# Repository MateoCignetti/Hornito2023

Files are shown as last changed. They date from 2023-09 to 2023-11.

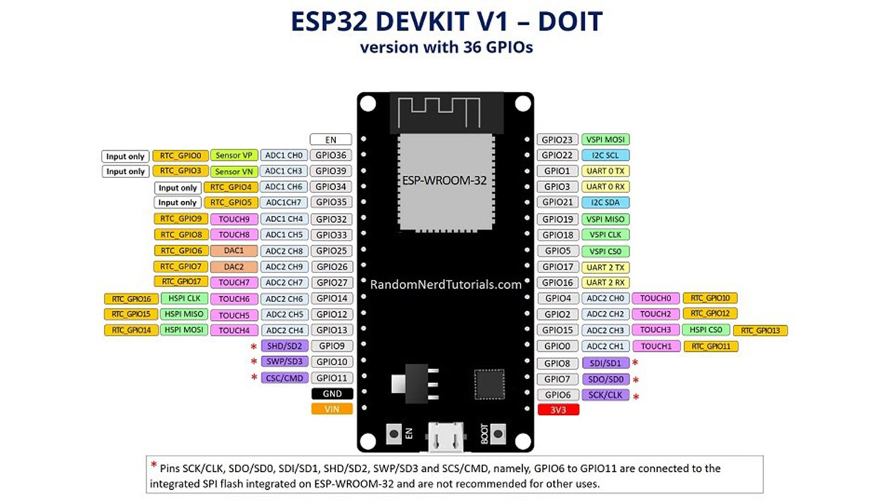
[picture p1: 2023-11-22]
Recursos/Esp32/esp32-devkit-v1-pinout.jpg

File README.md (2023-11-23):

## Trabajo práctico final de Técnicas Digitales III y Medidas Electrónicas II. UTN FR San Francisco

En este repositorio se encuentran subidos todos los archivos relacionados al trabajo práctico final las materias Técnicas Digitales III y Medidas Electrónicas II. Contiene archivos de programación de los microcontroladores, esquemáticos del circuito y de pcb, y recursos varios.

## Autores

- [ ] Alesandria, Alejo
- [ ] Cignetti, Mateo
- [ ] Delfino, Ramiro
- [ ] Galliano, Ignacio
- [ ] Rinaudo, Facundo
- [ ] Rodriguez, Manuel

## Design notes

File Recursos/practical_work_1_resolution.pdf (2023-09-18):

# Control de Potencia mediante TRIAC

Díaz, Matías - matidiaz2313@hotmail.com Previotto, Santiago – santiagopreviotto@gmail.com Ingeniería Electrónica - UTN Facultad Regional San Francisco Electrónica de Potencia – Ing. Giorgis, Alejandro

RESUMEN

A lo largo de este práctico podremos controlar la potencia administrada a una carga de tensión alterna mediante el uso de TRIAC. Para ello se tiene en cuenta la naturaleza de dicha carga como así también la potencia a controlar, para poder dimensionar el circuito de manera adecuada.
Palabras claves: TRIAC, potencia, carga, control.

INTRODUCCIÓN

Un TRIAC o Triodo para Corriente Alterna es un dispositivo semiconductor, de la familia de los tiristores. La diferencia con un tiristor convencional es que este es unidireccional y el TRIAC es bidireccional. De forma coloquial podría decirse que el TRIAC es un interruptor capaz de conmutar la corriente alterna.

Figura 1: Símbolo y estructura interna.

El TRIAC consta de 3 terminales y su estructura interna está compuesto por 4 capas que consta de seis regiones de dopado. El terminal definido como GATE está diseñado con el fin de que tenga contacto óhmico con las regiones N y P. Esto ayuda a que el dispositivo se active con polaridades positivas y negativas, es decir, como un arreglo de dos tiristores en antiparalelo.

La versatilidad del TRIAC y la simplicidad de su uso lo hace ideal para una amplia variedad de aplicaciones relacionadas con el control de corrientes alternas. Una de ellas es su utilización como interruptor estático ofreciendo muchas ventajas sobre los interruptores mecánicos convencionales, que requieren siempre el movimiento de un contacto, siendo la principal, la que se obtiene como consecuencia de que el TRIAC siempre se dispara cada medio ciclo cuando la corriente pasa por cero, con lo que se evitan los arcos y sobre tensiones derivadas de la conmutación de cargas inductivas que almacenan una determinada energía durante su funcionamiento. A continuación, se muestran algunas características importantes sobre los TRIAC:

- El TRIAC conmuta del modo de corte al modo de conducción cuando se inyecta corriente a la compuerta. Después del disparo la compuerta no posee control sobre el estado del TRIAC. Para apagar el TRIAC la corriente anódica debe reducirse por debajo del valor de la corriente de retención Iℎ.
- La corriente y la tensión de encendido disminuyen con el aumento de temperatura y con el aumento de la tensión de bloqueo.
- La aplicación del TRIAC, a diferencia del Tiristor, se encuentra básicamente en corriente alterna. Su curva característica refleja un funcionamiento muy parecido al del tiristor apareciendo en el primer y tercer cuadrante del sistema de ejes. Esto es debido a su bidireccionalidad.
- La principal utilidad del TRIAC es como regulador de potencia entregada a una carga, en corriente alterna.

Para poner en funcionamiento el mismo, se debe enviar un pulso de activación a través del terminal gate. Si el TRIAC está apagado no hay circulación de corriente entre las terminales MT2 y MT1 sin importar la polaridad del voltaje que se le aplique externamente. Para este caso, el TRIAC se comporta como un circuito abierto. Si el TRIAC está encendido, hay una condición de circulación de corriente de una terminal a la otra, esto depende de la polaridad del voltaje aplicado externamente. En el momento en que el voltaje en MT2 se hace más positivo, entonces la corriente circula de MT2 a MT1. En el momento en que el voltaje en MT1 se hace más positivo, entonces la corriente circula de MT1 a MT2. Para estas condiciones de operación el TRIAC se comporta como un interruptor cerrado.

Un optotriac (también conocido como optoacoplador) es un dispositivo que utiliza un TRIAC en su estructura interna, el cuál es activado mediante una luz infrarroja emitida por un fotodiodo hacia la gate del mismo. Cuando esta luz es interrumpida o bloqueada, el circuito se abre actuando como un interruptor abierto.
También, un optoacoplador puede contar en su estructura interna de un transistor como el PC817. Cuando se manda un pulso externo al fotodiodo, se emite un haz de luz a la base de un transistor interno, este se satura y entra en estado de conducción entre colector y emisor. Para este caso la impedancia entre colector y emisor es baja. Cuando no hay emisión de luz infrarroja, el fototransistor tiene alta impedancia entre colector y emisor y este no entra en conducción.

Figura 2: Optotransistor y optotriac.

DESARROLLO

Se propone realizar un controlador de potencia entregada a una carga, conocido comúnmente como dimmer. Se busca utilizar un circuito optoacoplador para separar la electrónica de control de la de potencia.
Para ello se selecciona el optoacoplador MOC3021, el cual es un optotriac, para controlar el ángulo de disparo y así la potencia en la carga. Además, se necesita un circuito de detección de cruce por cero, debido a que, por el lado del control, se debe conocer cuando la señal de alterna pasa por cero para tener la referencia y producir dicho disparo. Se utiliza un optoacoplador PC817, que es un optotransistor que conduce o no de acuerdo a si hay o no presencia de señal de potencia.
Según la hoja de datos del fabricante, el circuito de aplicación típico para el MOC3021 es el siguiente:

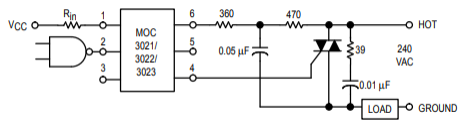
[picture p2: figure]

Figura 3: Aplicación típica del MOC3021.

El circuito consta de dos redes Snubber, una para proteger el TRIAC interno del MOC3021 (resistencia de 470 Ω y capacitor de 0.05 μF) y en la otra para proteger el TRIAC que manipula la carga (resistencia de 39 Ω y capacitor de 0.01 μF). Cabe aclarar que una red Snubber es un arreglo de elementos que sirve como protección del semiconductor de potencia ante las conmutaciones de conducción a no conducción y viceversa, soportando las variaciones bruscas de tensión que se producen, estas pueden estropear al dispositivo en cuestión. Para simplificar el circuito, se utiliza una única red Snubber RC para la protección del TRIAC que manipula la lámpara.
La carga a utilizar es una lámpara incandescente de 220 V − 42 W, debido a su naturaleza no se necesita manipular grandes corrientes, por lo que un TRIAC como el BT137 es más que suficiente y posee

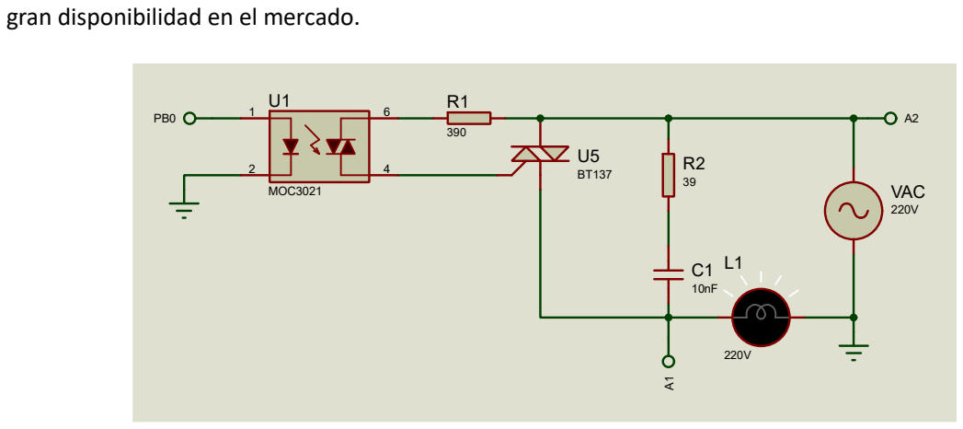
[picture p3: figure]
gran disponibilidad en el mercado.

Figura 4: Circuito de potencia.

A través del pin PB0 podemos controlar el optotriac MOC3021, este dispara la compuerta del TRIAC BT137 cuando se detecta el cruce por cero, la resistencia R1 limita la corriente que circula por la compuerta del mismo. Se conecta una red Snubber en paralelo al TRIAC, esta suprime corrientes no deseadas introducidas por la carga resistiva, las cuales pueden disparar el TRIAC en cualquier momento y causar problemas de operación.

Para el circuito de detección de cruce por cero, utilizamos un trasformador 220 V – 12 V para ingresar con una tensión más segura al optotransistor PC817. En el siguiente circuito, se puede observar la

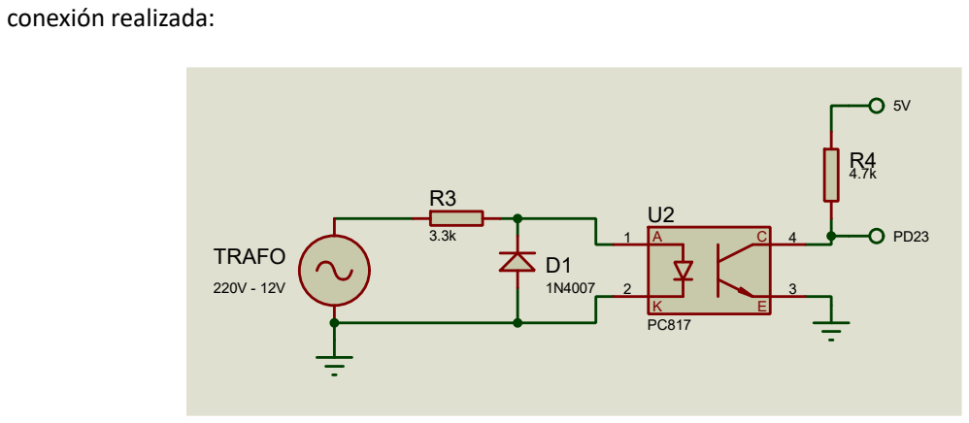
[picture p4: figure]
conexión realizada:

Figura 5: Circuito detector de cruce por cero.

Cuando la señal alterna está en un semiciclo positivo, el fototransistor se polariza, entrando en corte debido a que no hay diferencia de tensión entre colector y emisor, en cambio, con la señal alterna en un semiciclo negativo, el optotransistor no se polariza existiendo una diferencia de potencial entre el colector y emisor de VCC. El Diodo 1N4007 se encarga de proteger al optoacoplador de los semiciclos negativos y la resistencia de 3300 Ω limita la corriente por el mismo.

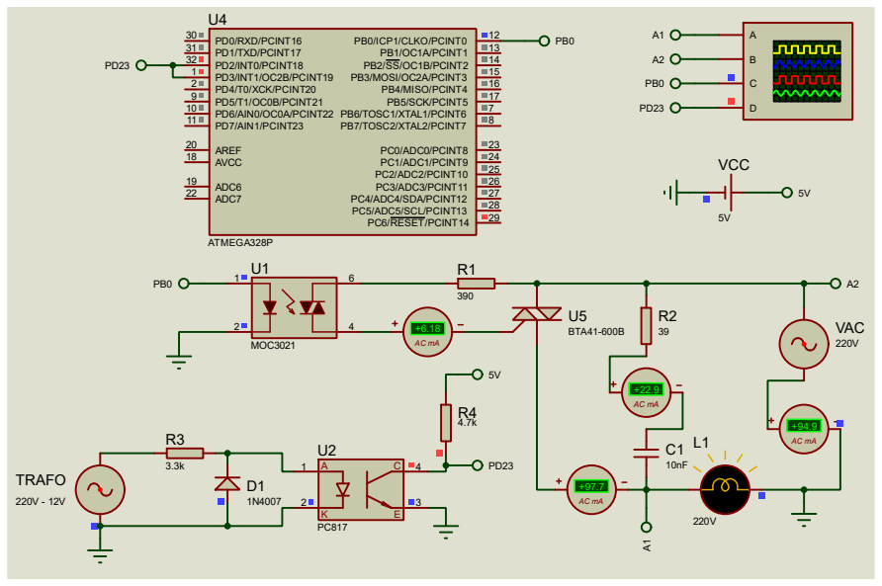
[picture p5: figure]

Figura 6: Diseño de circuito en Proteus con corrientes.

Se plantea el circuito de la figura 6 de control de potencia y se simula mediante el software Proteus, para poder observar que corrientes circulan por cada elemento y poder dimensionar correctamente los resistores y corroborar la selección del TRIAC. Cabe aclarar que el TRIAC BT137 no está disponible en el software, por lo que se selecciona el BTA41-600B de características similares.

La potencia que tiene que disipar la resistencia de la red Snubber es:

PR39 = (20 mA)

2 × 39 Ω = 15.6 mW

Por otro lado, la resistencia que limita la corriente por la compuerta del TRIAC tiene una potencia de:

PR390 = (6 mA)

2 × 390 Ω = 14.04 mW

Mediante esta última resistencia, se limita la corriente por la gate a 6 mA, lo cuál está dentro del valor recomendado por el fabricante.

IGT | Corriente de disparo de la gate | VD = 12 V; IT = 0.1 A; T2+ G+; Tj = 25 °C | 10 mA

La corriente por los terminales T1 y T2 del BT137 es aproximadamente 100 mA, de esta forma podemos decir que estamos dentro de los parámetros establecidos por el fabricante que plantea como máximo una corriente por terminales de 8 A.

IT(RMS) | Corriente RMS | Full sine wave; Tmb ≤ 102 °C | 8 A

Entonces teniendo las potencias disipadas, se buscan resistencias de 1/4 W, suficientes para manipular las corrientes en juego.

Ahora teniendo en cuenta el funcionamiento de ambos circuitos, tanto el de control de potencia como el de detección de cruce por cero, se necesita diseñar un programa para un microcontrolador capaz de controlar ambos circuitos. Se utiliza un microcontrolador de la marca Atmel, ATMEGA328P, posee 32kb de memoria flash, 2kb de memoria RAM y 1kb de EEPROM. Consta de 14 entradas/salidas digitales con 6 salidas PWM y 6 entradas analógicas. La siguiente ilustración describe la disposición de pines del mismo.

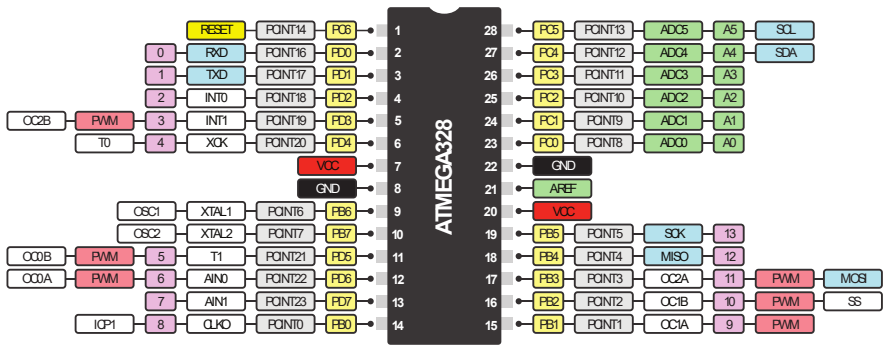
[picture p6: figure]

Figura 7: Pines del ATMEGA328P.

La idea principal del programa es evaluar el cruce por cero de la señal de control provista por el optoacoplador PC817 y en base a esto dar una señal al optoacoplador MOC3021 y así disparar el TRIAC. Entonces se utilizan dos interrupciones, INT0 e INT1, con la finalidad de detectar los flancos tanto de subida como de bajada de la señal del PC817. Luego ambas interrupciones realizan la misma secuencia, primero, un tiempo de espera que puede ser de hasta 10 ms, es decir la mitad del periodo de la onda de 50 Hz de alterna y luego, colocan en alto una salida digital PB0 durante 2 μs, tiempo recomendado de ancho del pulso para el disparo del BT137, según lo indica el fabricante. A continuación, se muestra el segmento de código en lenguaje C para el microcontrolador seleccionado.

/*
* Trabajo Práctico 1
* Electrónica De Potencia
* Ing. Giorgis, Alejandro
* UTN Facultad Regional San Francisco * Diaz, Matías; Previotto, Santiago
*/
/** \file main.c */

#define PRTC 50 // porcentaje de potencia entrada a la carga

/* librerías */
#include <avr/io.h>

#include <avr/interrupt.h>

#include <util/delay.h>

int main() {
cli(); | // desactiva las interrupciones globales
DDRB |= (1<<DDB0); // PB0 como salida (MOC3021) PORTB &=~ (1<<PORTB0); // PB0 inicializado en 0 DDRD &=~ (1<<DDD2); // PD2 como entrada (INT0)
DDRD &=~ (1<<DDD3); // PD3 como entrada (INT1)
// interrupción INT0 para flacos de subida
EICRA &=~ (1<<ISC00);
EICRA |= (1<<ISC01);
// interrupción INT1 para flacos de bajada EICRA |= (1<<ISC10);
EICRA |= (1<<ISC11);
// activación de INT0 e INT1
EIMSK |= (1<<INT0);
EIMSK |= (1<<INT1);
sei(); // activa las interrupciones globales while(1) {
}
return 0;
}

ISR(INT0_vect) { // rutina de interrupción INT0 _delay_us((int)(PRTC*(10000/100))
);
PORTB |= (1<<PORTB0);
_delay_us(2);
PORTB &=~ (1<<PORTB0);

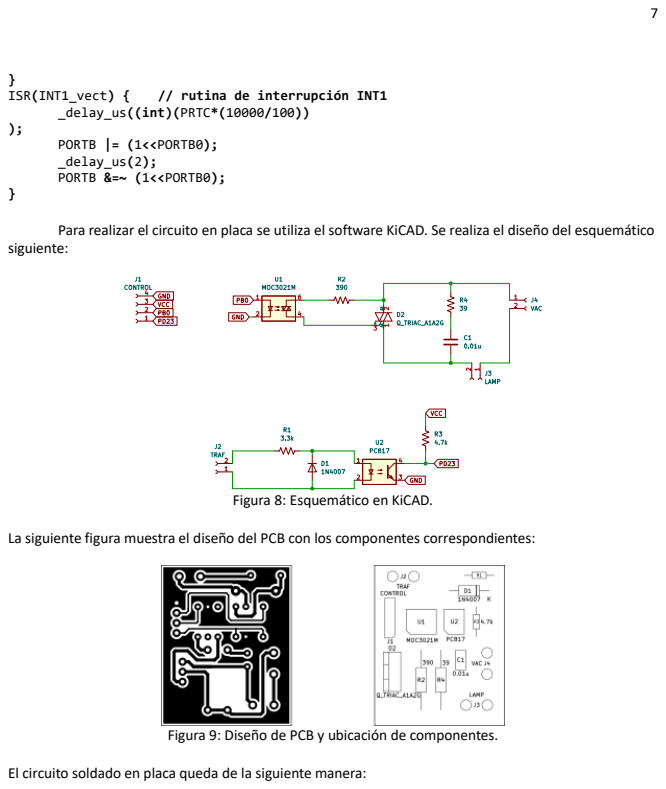
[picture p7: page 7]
ISR(INT1_vect) {; // rutina de interrupción INT1; _delay_us((int)(PRTC*(10000/100)); PORTB |= (1<<PORTB0); _delay_us(2); PORTB &=~ (1<<PORTB0);; siguiente:

Para realizar el circuito en placa se utiliza el software KiCAD. Se realiza el diseño del esquemático

Figura 8: Esquemático en KiCAD.

La siguiente figura muestra el diseño del PCB con los componentes correspondientes:

Figura 9: Diseño de PCB y ubicación de componentes.

El circuito soldado en placa queda de la siguiente manera:

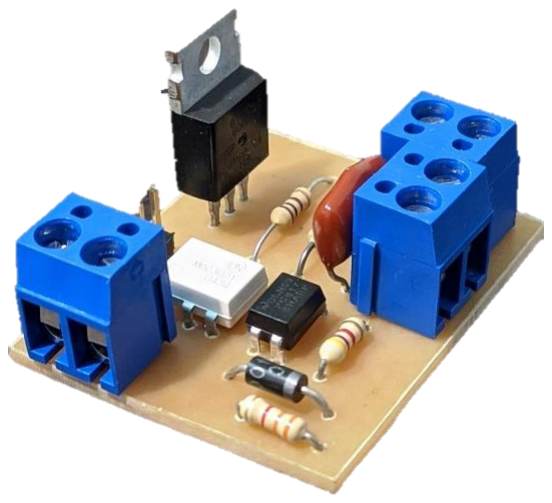
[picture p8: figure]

Figura 10: Placa terminada.

Para los ensayos de laboratorio se prueba primero el circuito de detección de cruce por cero, donde se utiliza un transformador de 220V-12V y la salida de control del PC817 conectada al microcontrolador en los pines PD2 y PD3 para detectar los flancos de subida y de bajada. Se mide con el osciloscopio el pulso en la salida PB0 del ATMEGA328P y se observa el pulso de 2 μs correspondiente, lo que verifica el funcionamiento óptimo.

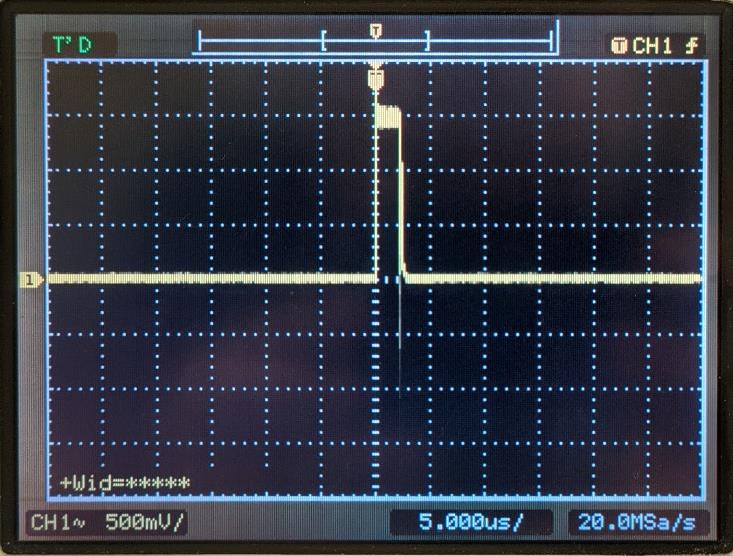
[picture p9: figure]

Figura 11: Pulso de PB0.

Ahora se varía el porcentaje de potencia entrada en la programación y se observa en el osciloscopio la señal entrada a la carga (señal de color verde) y la señal de 220V de línea (señal de color amarillo).

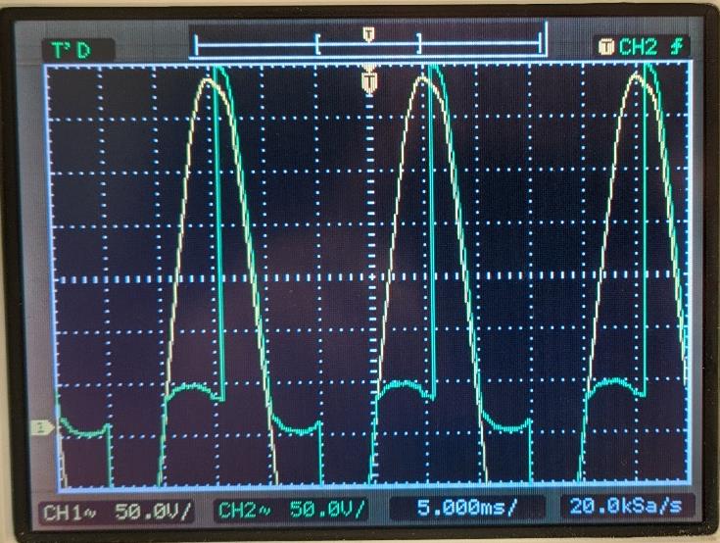
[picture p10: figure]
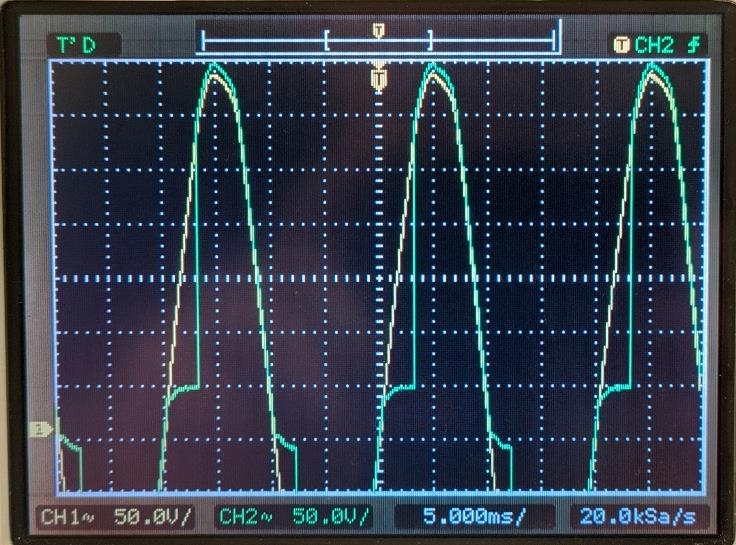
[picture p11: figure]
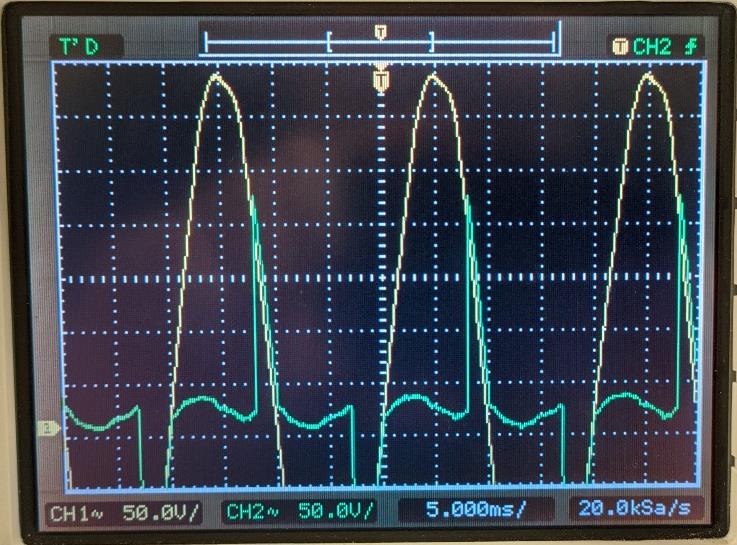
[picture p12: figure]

Figura 12: a) Señal al 25%. b) Señal al 50%. c) Señal al 75%.

CONCLUSIONES

Se puede destacar que el control de potencia mediante un TRIAC, es necesario un circuito dedicado a la detección del cruce por cero, de esta manera se tiene referencia de cuando la señal de línea es nula y poder referenciar bien el lapso de tiempo disponible para disparar el TRIAC. Además, se puede decir, que debido al control realizado como se describe a lo largo del práctico, la carga, en este caso una lámpara, ante un porcentaje de señal muy bajo (<20%), no llega a iluminar debido a que el filamento no se enciende correctamente con ese voltaje aplicado.

a) b)

c)

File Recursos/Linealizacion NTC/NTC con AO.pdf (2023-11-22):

# Linealización de termistores NTC

Autor: Felix Mateo Lazaro

RESUMEN
El objeto del presente trabajo es el estudio de las técnicas existentes de linealización para termistores NTC, así como el estudio de técnicas nuevas en base a la linealización con amplificadores logarítmicos, ademas del uso de técnicas con amplificadores operacionales para mejorar el auto calentamiento de los termistores NTC.
Se abordan primeramente las técnicas mas difundidas de linealización, realizando después un estudio mas detallado del resto.
Palabras clave
Termistor NTC. Linealización de Termistores. Medida de temperatura. Instrumentación. Amplificador Logarítmico.

Abstrat
The purpose of this work is the study of technical techniques of linearization for NTC thermistors, as well as the study of new techniques based on linearization with logarithmic amplifiers, in addition to the use of techniques with operational amplifiers to improve the self-heating of NTC thermistors.
The most widespread linearization techniques are first approached, then carrying out a more detailed study of the rest.
Keywords
NTC Thermistor. Thermistor Linearization. Temperature measurement. Instrumentation. Logarithmic Amplifiers.

## Sumario

1.6 Circuito logarítmico basado en la curva exponencial de descarga de un condensador.........8

# 1. Introducción a los termistores NTC

Un termistor NTC es un sensor de temperatura por resistencia, que varia su valor con la temperatura con un coeficiente negativo. La forma de la curva característica de esta resistencia puede verse en la figura 1 (curva A). Se ve que el valor de esta varia de forma negativa con un aumento de temperatura.
El uso de termistores NTC en la medida de temperaturas está ampliamente difundido dentro de la industria. La no linealidad del comportamiento de estos componentes restringe su uso al control de temperatura de diferentes procesos industriales, siendo mas difícil su utilización en la medida de estas de una forma precisa y lineal.

Existen diferentes métodos o circuitos de linealización para estos termistores que en la actualidad permiten su uso mas plenamente.

## 1.1 Ecuación de Steinhart-Hart

En 1968 Steinhar y Hart desarrollaron un modelo matemático para la característica R-T (resistencia - temperatura) de un termistor NTC para hacer mediciones precisas de temperatura en estudios oceánicos.
La ecuación de Steinhart-Hart tiene tres términos y es el modelo popular mas usado para el modelado R-T de termistores NTC. La ecuación en su forma general es la siguiente:
1
T

=C1+C2

·ln RT+C3

·(ln RT

)

3
[1]

Donde T es la temperatura absoluta medida en Kelvin (0ºC = 273,15 K), y RT la resistencia en Ω (ohmios). Los términos C1, C2, y C3 son las constantes de Steinhart-Hart del termistor.
Para simplificar a ecuación [1] a dos términos puede usarse en algunos casos la siguiente ecuación:
1
T

=C'

1+C '
2

·ln(RT

) | [2]

Denominándose ecuación simplificada de Steinhart-Hart
Donde las constantes C’1 y C’2 son las nuevas constantes del termistor. Téngase en cuenta que C’1 ≠ C1 y C’2 ≠ C2.

## 1.1.1Ecuación de Steinhart-Hart simplificada normal

La ecuación simplificada de Steinhart-Hart puede ponerse de la siguiente manera:

RT=A·e

(

B
T

)
[3]

Denominamos a esta, ecuación normal de un termistor NTC donde las nuevas constantes A y B valen:

A=e

(

C ' 2
C ' 1

)
y | B=

1
C'
2
Donde A es una constante que depende del termistor NTC, y representa el valor de la resistencia del termistor NTC cuando la temperatura es supuestamente infinita.
B es la resistencia característica del material de que está hecho el termistor NTC. Su valor esta comprendido entre 2000K y 4000K.
Calculo de las constantes A y B del termistor para la nueva ecuación normal
Los fabricantes de termistores NTC normalmente dan tablas relacionando los valores de RT y T, pero no dan los valores de de las constantes A y B por lo que hay que calcularlas para el intervalo de temperaturas en el que el termistor va a funcionar, de manera que se obtenga la mayor precisión posible en dicho intervalo.
Los valores de A y B hay que calcularlos según los valores de la resistencia RT a diferentes temperaturas. Para ello realizamos la siguiente consideración:

A=R0
- e

−B
T0 | donde igualando A para dos valores de R0 y T0 se obtiene: | [4]

R1

- e

−B
T1 =R2
- e

−B
T2 | de donde | B=

ln R1−ln R2
1
T1

−

1
T2

siendo R1 y R2 las resistencias del termistor NTC a las temperaturas T1 y T2 respectivamente. Una vez conocido B podemos calcular el valor de A sin mas que sustituirlo en la ecuación [4] para una temperatura y resistencia de referencia (R0 y T0 a 25ºC, o 0ºC por ejemplo).

Nota: Al valor nominal de un termistor NTC se le denomina R25 y es la resistencia de dicho termistor a la temperatura de 25ºC. Puede haber termistores con un valor nominal entre 15Ω y 470KΩ.

Los márgenes de temperatura entre los que pueden trabajar estos termistores esta normalmente entre -55ºC y 125ºC, con una tolerancia del valor nominal comprendida entre ±10% y ±5%.

## 1.1.2Calculo de las constantes de Steinhart-Hart para la ecuación general

Teniendo la ecuación general, podemos plantear un sistema de tres ecuación con tres incógnitas (las constantes C1, C2, y C3) sabiendo los valores de RT para tres valores de T. Así tendremos:
1
T1

=C1+C2

·ln R1+C3

| ·(ln R1

)

| 3
Temperatura mínima del intervalo considerado

1
T2

=C1+C2

·ln R2+C3

| ·(ln R2

)

| 3
Temperatura media del intervalo considerado

1
T3

=C1+C2

·ln R3+C3

| ·(ln R3

)

| 3
Temperatura máxima del intervalo considerado

Haciendo las sustituciones siguientes para los términos de T, y R podemos simplificar la nomenclatura de estas ecuaciones:
A1=C1+C2
·D1+C3 | · E1

A2=C1+C2

·D2+C3 | · E2

A3=C1+C2

·D3+C3 | · E3

Operando se obtienen los valores de C3, C2, y C1 , que usando la notación Xnm=Xn-Xm se obtiene:

C3=

A23 ·D12−A12 ·D23

E23 ·D12−E12 ·D23

; | C2=
| | A12
| | D12

−C3
·

E12

D12

; C1=A2−C2

- D2−C3
·E2

Sustituyendo de nuevo por sus valores se obtiene:

C3=

(

1
T2

−

| 1
| T3 )·ln R1
| R2

−(

1
T1

−

| | 1
| | T2

)·ln

R2
R3

((ln R2

)

3−(ln R3
)
| 3 )·ln R1
| R2

### −((ln R1

)

| | 3−(ln R2
)

3
)·ln

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
ln R1
R2

−C3
·

(ln R1

)

3−(ln R2
)

3
ln R1
R2

C1=

1
T2

−C2

- ln R2−C3

·(ln R2

)

3

Una vez calculadas las constantes C1, C2, y C3 para un termistor en concreto podemos calcular una temperatura dada sabiendo su valor RT para esa temperatura.

# 2. Uso de amplificadores operacionales con termistores NTC

Los termistores NTC suelen usarse en circuitos linealizados con una resistencia en serie, lo cual dificulta su utilización para obtener sensibilidades suficientes sin producir demasiado auto calentamiento. El uso con amplificadores operacionales minimiza este problema.

## 1.2 Circuitos para la obtención de la curva de la resistencia

La obtención de la curva de la resistencia RT de un termistor se realiza alimentan dolo con una corriente constante de forma que se obtiene la siguiente igualdad:
V0=I
cte ·RT

Si la corriente constante I es muy pequeña, el auto calentamiento que se producirá en el termistor sera muy pequeño también. Los circuitos de la figura 1 cumplen con esta condición.

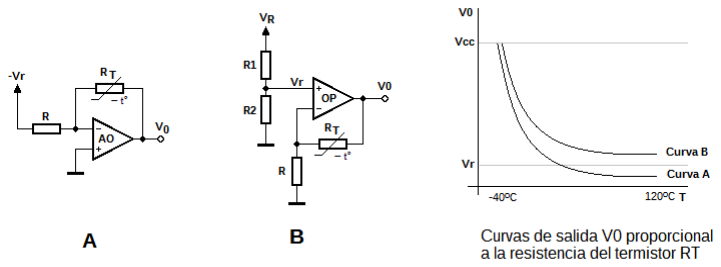
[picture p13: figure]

Figura 1: Circuito inversor (A) y no inversor (B). Y curvas de V0 directamente proporcionales a la resistencia RT del termistor para los dos circuitos. Planteando las ecuaciones que rigen los circuitos A y B se obtiene:

A) V0=

Vr

·RT
R

=I
cte ·RT | V0 es directamente proporcional a RT
B) V0=Vr

·(1+

RT
R

### )=Vr+I

cte ·RT V0 es directamente proporcional a RT mas un valor (Vr)

En algunas aplicaciones es posible que este valor añadido Vr sea problemático por lo que se deberá de utilizar preferentemente el circuito A, o añadir un restador al circuito B que reste el valor de Vr. Este valor de Vr debe de ser lo mas pequeño posible ya que actúa como un valor constante que limita el rango de salida de V0, que valdrá desde Vr hasta la tensión de alimentación +VCC

## 1.3 Circuitos para aumentar la sensibilidad en la zona de baja resistencia

Si se alimenta el termistor NTC con una tensión constante se obtiene una variación de la corriente que circula por el mismo con la variación de la resistencia RT del termistor. El planteamiento es el siguiente:

I

0=

V cte
RT

Ya que la corriente que circula por RT debe de ser muy pequeña para reducir el auto

calentamiento del termistor, la tensión Vcte también debe de ser muy pequeña. Los circuitos de la figura 2 cumplen con esta condición.

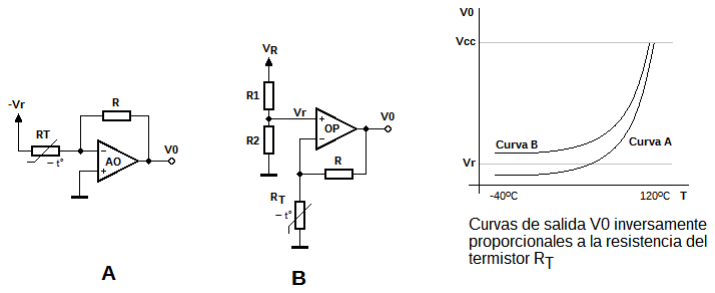
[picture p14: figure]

Figura 2: Circuito inversor (A) y no inversor (B). Y curvas de V0 inversamente proporcionales a la resistencia RT del termistor para los dos circuitos. Planteando las ecuaciones que rigen los circuitos A y B se obtiene:

A) V0=

Vr

·R
RT

=

K
RT

V0 es inversamente proporcional a RT

B) V0=Vr

·(1+

R
RT

)=Vr+

K
RT

V0 es inversamente proporcional a RT mas un valor (Vr)

El valor añadido Vr es problemático por lo que se deberá de utilizar preferentemente el circuito Ar. Este valor de Vr debe de ser lo mas pequeño posible ya que actuá sobre el auto calentamiento del termistor a la vez que limita el rango de salida de V0, que valdrá desde Vr hasta la tensión de alimentación +VCC
En los dos casos el auto calentamiento del termistor depende de la tensión de referencia constante Vr por lo que esta debe de ser lo mas pequeña posible (en torno a 1V o menos).

## 1.4 Circuitos de linealización por resistencia serie

La linealización clásica de un termistor NTC es conectandole una resistencia en serie de forma que se obtiene una linealización de la tensión en sus extremos. Este método es muy poco sensible en la zona de resistencia baja. Si se utiliza un amplificador operacional para medir la corriente que circula por el termistor en lugar de medir la tensión se obtienen mejores resultados. En la figura 3 se pueden ver dos circuitos que funcionan de esta manera.

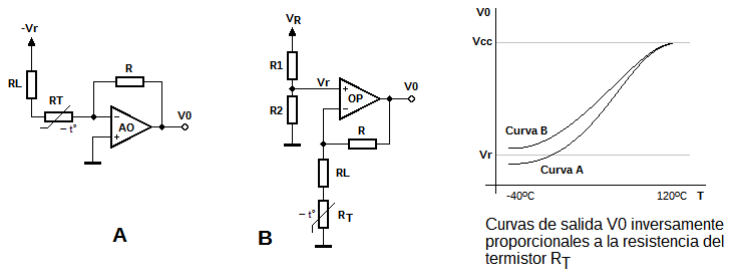
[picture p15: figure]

Figura 3: Circuito inversor (A) y no inversor (B). Y curvas de V0 inversamente proporcionales linealizadas para los dos circuitos.
Planteando las ecuaciones que rigen los circuitos A y B se obtiene:
A) V0=

Vr

- R
RT+RL

=

K
RT+RL
B) V0=Vr

·(1+

R
RT+RL

)=Vr+

K
RT+RL

El valor añadido Vr es problemático por lo que se deberá de utilizar preferentemente el circuito A. Este valor de Vr debe de ser lo mas pequeño posible ya que actúa como un valor constante que limita el rango de salida de V0, que valdrá desde Vr hasta la tensión de alimentación +VCC
En los dos casos el auto calentamiento del termistor depende de la tensión de referencia constante Vr y por la limitación de la corriente que RL produce en el termistor, por lo que en este caso la tensión de referencia Vr puede ser mayor que la utilizada en los circuitos de la figura 2.

# 3. Circuitos de linealización con circuitos logarítmicos

Si se utiliza una aproximación a la ecuación normal del termistor (ecuación [3]) para realizar la linealización, podemos usar un circuito logarítmico de forma que se obtiene una linealización bastante precisa para la mayoría de las aplicaciones.

## 1.5 Circuito logarítmico basado en la curva exponencial de un diodo

Usando un amplificador logarítmico para una lectura de la resistencia se obtiene en principio, una linealización de la función exponencial. En realidad obtendremos la función Cte/T (función inversa de la temperatura), que si utilizamos un circuito divisor podemos obtener una función lineal con la Tª.
En la figura 4 podemos ver el circuito de linealización para un termistor NTC.

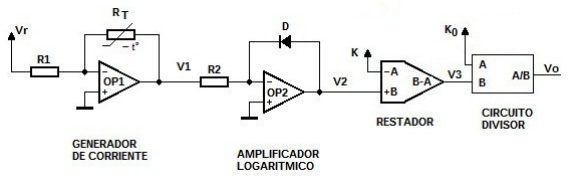
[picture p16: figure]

Figura 4: Circuito logarítmico para la linealización de un termistor. El funcionamiento es como sigue: El circuito del operacional OP1 funciona como una fuente de corriente, de tal manera que la salida V1 es una tensión proporcional a RT, y por lo tanto la función exponencial de la temperatura T. La ecuación siguiente indica en que proporción se obtiene V1.

V1=

−Vr
R1
- RT=

−Vr
R1
- A· e

(B/T )
[5]

El amplificador operacional OP2 funciona como un amplificador logarítmico cuyas características dependen del diodo D. La ecuación por la que se rige el diodo es la siguiente:

I D=I
S

(e

(V D/VT

)
) | de donde | V D=VT
·ln

I D
I S

[6]

Donde:
VD = tensión en el diodo para una corriente ID, (VD coincide con V2). VT = tensión constante que depende del diodo utilizado.
IS = corriente constante que depende del diodo utilizado.
ID = corriente por el diodo, que en el circuito del amplificador OP2 será V1/R2. También tenemos que:

I D=

−V1
R2

y V2=V D

Sustituyendo estas ecuaciones y la ecuación [5] en la [6] y operando se obtiene:

V2=V D=VT
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
- ln

V r

- A
I S
- R1

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
Si utilizamos un restador a la salida de OP2 para restar la constante K obtendremos una V3 que valdrá VT·B/T. Si esta tensión se lleva al divisor se obtiene una tensión V0 lineal con la temperatura T.
Se tiene por lo tanto que:
V3=V2−K | y | V0=

K0
V3

Sustituyendo estas ecuaciones se obtiene:

V0=

K0

·T
VT

·B

De donde T=

V0

·VT

·B
K0

En la figura 5 puede verse el método de conversión de forma grafica.

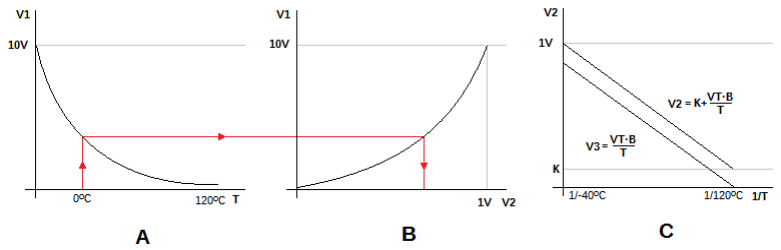
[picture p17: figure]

Figura 5: Curva de la resistencia RT (A). Del logaritmo (B). Salida lineal con 1/T (C).

El amplificador OP2 debe de ser de precisión ya que la variación de la tensión V2 sera entre 0 y 1V aproximadamente. Probablemente se necesitará amplificar esta tensión hasta 10V o mas antes de entrar en el circuito restador, de forma que V3 esté entre los valores de 0,1V y 10V para obtener una tensión a la salida del divisor entre 10 y 0,1V respectivamente.
Para finalizar hay que tener en cuenta que la temperatura T esta dada en kelvin, por lo que si queremos obtener una salida en función de la Tª en ºC tendremos que utilizar otro restador que reste la parte proporcional de 273,15 K (constante de conversión de Kelvin a ºC) a la tensión V0.

## 1.6 Circuito logarítmico basado en la curva exponencial de descarga de un condensador

Este circuito de linealización se basa en la descarga exponencial de un condensador a través de una resistencia. En realidad lo que se obtiene con el condensador es la curva exponencial (del tipo e

-X) a través del tiempo, por lo que si realizamos de alguna manera la la comparación de esta función con la función exponencial de RT (del tipo e¹/X)obtendremos la linealización de la Tª. En la figura 6 podemos ver el circuito de descarga exponencial y comparación completo para una tensión V1 dada.

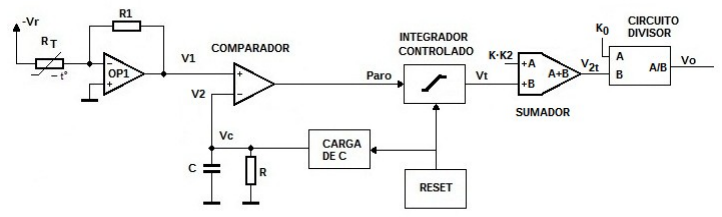
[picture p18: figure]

Figura 6: Circuito de linealización de termistor NTC con condensador.

El funcionamiento de este circuito es el siguiente:
La tensión V1 inversamente proporcional a la resistencia del termistor NTC se compara con la tensión Vc de descarga exponencial del condensador C, que cuando son iguales el comparador activa la señal de Paro del integrador, de esta forma se obtiene una tensión Vt proporcional a V1 y por lo tanto a la temperatura (aunque es la función inversa de la Tª). A esta tensión se le suma el valor de unas constantes que aparecen en el circuito de linealización y la salida se lleva a un circuito divisor para calcular la inversa, obteniéndose una tensión Vo directamente proporcional a la temperatura del termistor NTC en grados Kelvin. A este valor de V0 podemos restarle la tensión correspondiente a 0ºC (273,15 K) obteniendo la temperatura en ºC.
El planteamiento de las ecuaciones es el siguiente:

V1=

Vr

·R1
RT

=

Vr

- R1
A·e⁽B/T )=

Vr

·R1
A
- e

(−B/T )
[7]

V2=V C=V·e

−t
R·C | [8]

Se tiene pues que el comparador dará la señal de Paro cuando V1 = V2 por lo que igualando las ecuaciones [7] y [8] se obtiene:

ln

V r

- R1
V·A

−

B
T

=

−t
R·C

de donde B·R·C
T

=t+R·C·Ln

Vr

·R1
V·A
=t+K | [9]
Donde | K=R·C·Ln

Vr

·R1
V·A

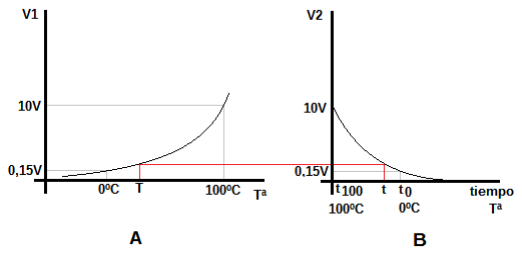
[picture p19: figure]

Figura 7: Tensiones V1 (A) y V2 (B).

Se tiene por lo tanto que K es una constante que depende de los valores de los componentes del circuito. Vr debe de ser del orden de 1V a 0,1V para evitar el auto calentamiento del termistor. La resistencia R1 se calcula en base a obtener un rango de salida V1 en torno a los 10V como máximo en la zona de temperaturas en que nos interese actuar. Y R y C podemos seleccionarlos para la constante de tiempo que nos interese. Valores normales obtenidos para K son en torno a 0,01.
El circuito integrador funcionará un tiempo t, de donde se obtiene una tensión Vt proporcional a t. Por lo que Vt = K2 · t. Donde K2 es una constante que dependerá del integrador.
Se obtiene pues de la ecuación [9] que:
B·R·C
T
=t+K | y en tensiones | B·R·C T
=

Vt
K2

+K

Donde K2 es una constante que depende del integrador. De aquí se obtiene:
B·R·C·K2
T

=Vt+K·K2

Esto quiere decir que si a la tensión Vt obtenida a la salida del integrador controlado le sumamos el valor K·K2 obtendremos:

V2t=Vt+K·K2=

B·R·C·K2
T

Si se utiliza un circuito divisor a continuación de este sumador podemos obtener una tensión V0 proporcional a T, obteniendo una V0 ≡ K0 · T. A la salida del circuito divisor se tiene por lo tanto:

V0=

K0

V2t

(t)

=

T ·K0
B·R·C·K2

de donde T=V0
- B·R·C·

K2
K0

Hay que tener en cuenta que la temperatura T esta dada en grados Kelvin por lo que si se quiere obtener una salida en grados centígrados se deberá de utilizar un restador que ajuste la salida en la parte proporcional de 0ºC (273,15 K). Existen circuitos multiplicadores divisores que realizan la función A/B-Z como el AD734, por lo que si utilizamos este CI no tendremos que usar un restador adicional a la salida del circuito divisor.

# 4. Circuito de linealización utilizando la ecuación de Steinhart-Hart (con microprocesador)

Dada la ecuación general de Steinhart-Hart y calculadas sus constantes C1, C2, y C3 según las ecuaciones del apartado “Calculo de las constantes de Steinhart-Hart para la ecuación general” en la página 3 para el termistor que se utilice, se puede usar el siguiente circuito para la medida de la resistencia RT y procesar este valor con un microprocesador de acuerdo con la ecuación general de Steinhart-Hart. La linealización es la mas precisa que se puede obtener.

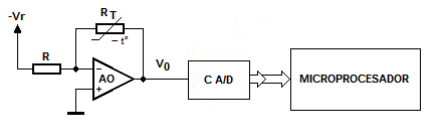
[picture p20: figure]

Figura 8: Circuito para la medida de la Tª linealizada con microprocesador.
El funcionamiento es el siguiente. El amplificador OP funciona como un generador de corriente constante por lo que V0 será proporcional a la resistencia del termistor. Este valor analógico se convierte en digital con un conversor A/D (analógico/digital) que está controlado por un circuito con microprocesador, el cual trata numéricamente este valor medido de RT para calcular la Tª en base a la ecuación de Steinhart-Hart.

# 5. Conclusiones

El uso de amplificadores operacionales para la conexión de termistores NTC permite disminuir el auto calentamiento del termistor a la vez que aumenta la sensibilidad en la zona de resistencia baja. Esto añadido al uso de circuitos logarítmicos permite una linealización completa de la Tª basándose en al ecuación simplificada de normal del termistor. Esta linealización se puede mejorar aún mas usando un circuito microprocesador que calcule la Tª en base a la medida de la resistencia RT con un circuito de corriente constate y la ecuación general de Steinhart-Hart.

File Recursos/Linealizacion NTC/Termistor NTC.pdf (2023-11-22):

## TERMISTOR NTC

Un termistor NTC es un sensor de temperatura por resistencia, que varia su valor con la temperatura con un coeficiente negativo. La forma de la curva característica de esta resistencia puede verse en la figura 2 curva D. Se ve que el valor de esta varia de forma negativa con un aumento de temperatura. Los puntos rojos corresponden a los valores reales (medidos empíricamente) de un termistor NTC de valor nominal 150W a 25ºC.
Se puede calcular la ecuación que rige la resistencia del termistor NTC siendo la siguiente:

RT=A·e

B
T
(1)

siendo:
RT = el valor de la resistencia a la temperatura T (en grados Kelvin. 0ºC=273,15ºK).
A = una constante que depende del termistor NTC, y representa el valor de la resistencia del termistor NTC cuando la temperatura es supuestamente infinita.
B = es la resistencia característica del material de que está hecho el termistor NTC. Su valor esta comprendido entre 2000ºK y 4000ºK.

Los fabricantes no suelen dar los valores de A y B por lo que hay que calcularlos según los valores de la resistencia RT a diferentes temperaturas. Para ello realizamos la siguiente consideración:

A=R0
- e

−B
T0 | donde igualando A para dos valores de R0 y T0 obtenemos: | (2)

R1

- e

−B
T1 =R2
- e

−B
T2 | de donde | B=

ln R1−ln R2
1
T1

−

1
T2

(3)

siendo R1 y R2 las resistencias del termistor NTC a las temperturas T1 y T2 respectivamente. Una vez conocido B podemos calcular el valor de A sin mas que sustituirlo en la ecuación (2) para una temperatura y resistencia de referencia (R0 y T0 a 25ºC, o 0ºC por ejemplo).

Como hemos visto la curva de la resistencia del termistor NTC no es lineal, pero podemos utilizar unos circuitos sencillos que ayudan a linealizar su característica de forma apreciable. En la figura 1 podemos ver algunos de estos circuitos, obteniendoasé las curvas respectivas de la figura 2. Como puede verse en la misma se ha mejorado la variación de la respuesta a la temperatura. En los casos E y F se ha obtenido que la variación aumenta en la zona de mayor temperatura (o menos sensibilidad de la resistencis NTC), lo que facilita su uso en algunos circuitos.

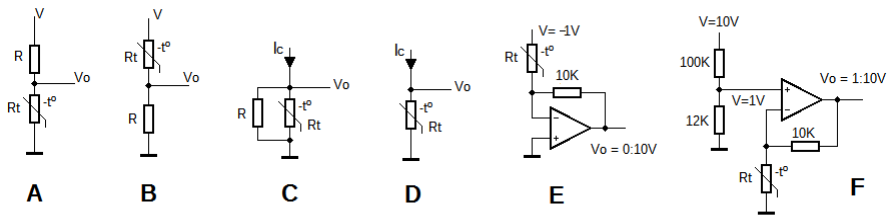
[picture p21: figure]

Figura 1: Circuitos de linealizacion de un termistor NTC.

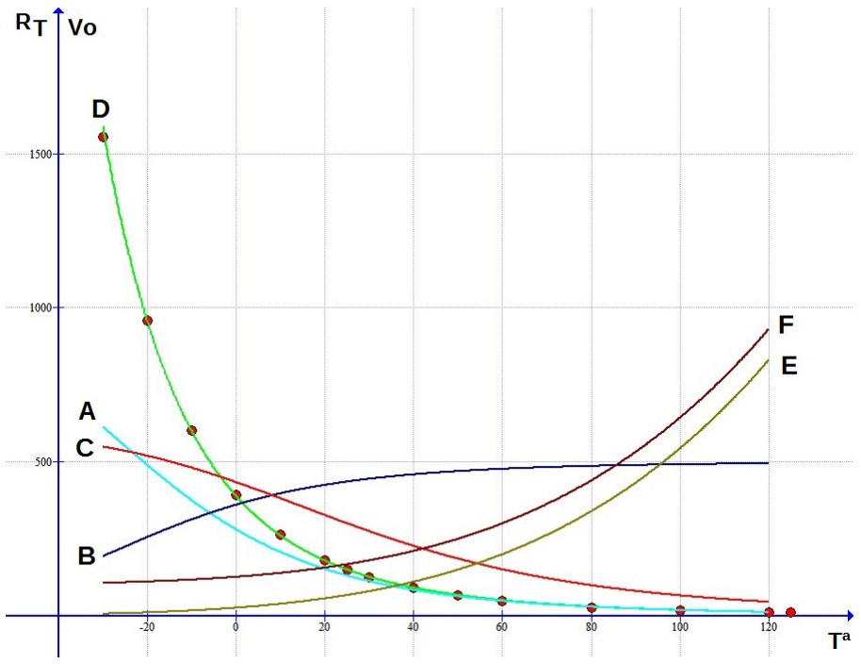
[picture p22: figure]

Figura 2: Resistencia de un termistor NTC y curvas de linealización.
Los márgenes de temperatura entre los que pueden trabajar estos termistores estra normalmentre entre -55ºC y 125ºC, con una tolerancia del valor nominal comprendiada entre ±10% y ±5%.
El valor nominal de la resistencia puede estar entre 15W y 470KW, y se denomina R25 siendo el valor de la resistencia a la temperatura de 25ºC.

Las ecuaciones que rigen los circuitos de linealización de la figura 1 son las siguientes:

CASO A:

V0=

V·RT
RT+R

=

V·A·eB/ T
A·eB/ T
+R

(4)

CASO B:

V0=

V·R
RT+R

=

V·R
A·eB/ T
+R

(5)

CASO C:

V0=I C

·(RT∥R)=I C

RT

- R
RT +R

=IC

A·eB/T
- R
A·eB/T
+R

(6)

CASO D:

V0=I C · RT=IC · A·eB/T
(7)

Este circuito no es de linealización propiamente dicho, pero permite usar el termistor NTC para detección de una temperatura concreta de forma bastante precisa.

Si queremos utilizar un procesador que linealice el valor de T podemos utilizar la siguiente ecuación:

T=

B

ln

V 0
I C · A

(8)

Siendo IC un valor constante conocido, y V0 los valores de salida obtenidos para todo el rango de temperatura.

CASO E:

V0=

R·V
RT

=

R·V
A·eB/ T

(9)

CASO F:

V0=V·(1+

R
RT

)=V·(1+

R
A·eB/T
) | (10)

LINEALIZACION DE LOS CASOS E Y F CON RESISTENCIA SERIE
Si conectamos una resistencia en serie (RS) al termistor NTC en el circuito de linealización E de la figura 1, podemos obtener una mayor linealización de la salida V0 en dicho circuito. Dependiendo del valor de esta resistencia RS con relación al valor R25 del resistor NTC podemos obtener mayor o menor linealizacion. En la figura 3 podemos ver las curvas de linealizacion para valores de RS crecientes (curvas 1 a 4) en referencia a la curva E obtenida sin resistencia serie.

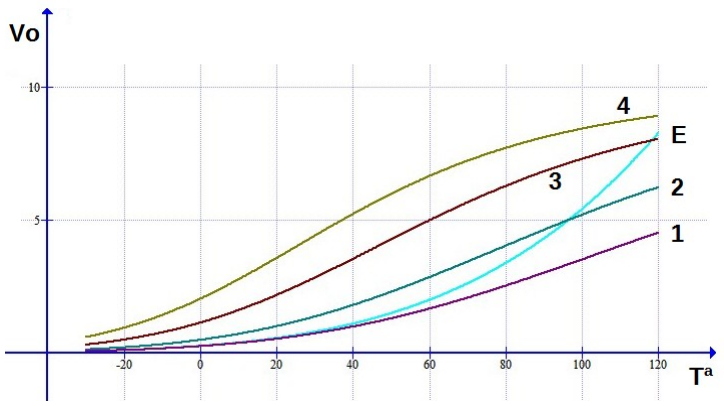
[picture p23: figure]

Figura 3: Linealización del caso E con resistencia serie.

La ecuación que rige el circuito en este caso es la siguiente:

V0=

R·V
RS+RT

=

R·V
RS+ A·eB/ T

[11]

Puesto que la tensión de salida V0 disminuye al aumentar la resistencia serie, el numerador de la ecuación [11] deberá de aumentar para mantener una salida V0 adecuada. Esto supone aumenar V, R o ambos.
Esta resistencia serire RS permite aplicar una tension de referencia V mayor, o disminuir la corriente que circula por el termistor NTC reduciendo de esta manera el autocalentamiento.

Asímismo en en circuito F de la figura 1 podemos aplicar la misma linealización, obteniendo resultados similares. La ecuación que rige el circuito F linealizado es la siguiente:

V0=V·(1+

R
RS+RT

)=V·(1+

R
RS+ A·eB/ T
) | [12]

CIRCUITOS DE DETECCION DE TEMPERATURA
En la figura 4 podemos ver varios circuitos para la detección de una temperatura concreta.

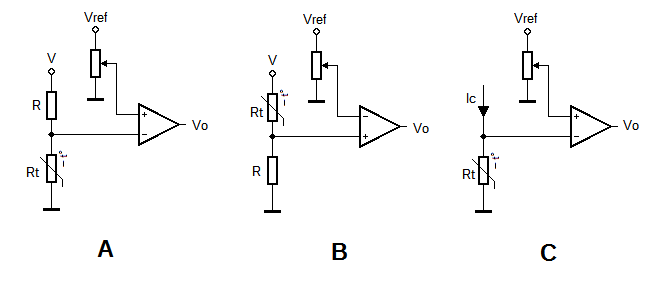
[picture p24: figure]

Figura 4: Circuitos detectores de temperatura con NTC.

En los circuitos A y B la resistencia R debe de ser de un valor tal que no permita un autocalentamiento escesivo del termistor NTC por la potencia disipada por efecto Joule en cualquiera del rango de valores que puede alcanzar el termistor, sobre todo en la zona de mayor tempertatura (o menor resistencia). En el caso del circuito C, la corriente IC debe de ser de un valor que no permita un autocalentamiento perceptible por la potencia disipada en la zona de menor temperatura (o mayor resistencia).
También podemos utilizar los circuitos de linealización E y F de la figura 1 conectados a un comparador para detectar una temperatura concreta con mas sensibilidad en la zona de mayor tempertarura. En estos casos la tensión que alimenta el termistor NTC (en la figura 1 V=1V) debe de ser lo suficientemente pequeña para que no produzca un autocalentamiento excesivo.

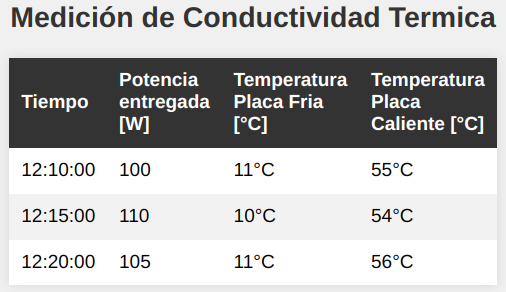
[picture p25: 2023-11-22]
Recursos/html_idea.png

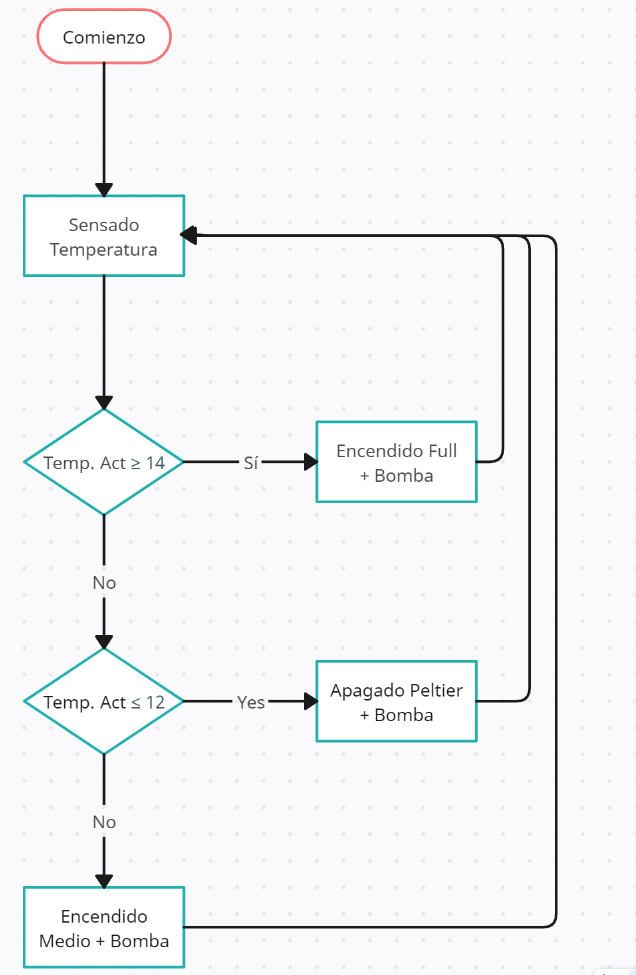
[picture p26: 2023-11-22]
SistRefrig/DiagramaFlujo.png

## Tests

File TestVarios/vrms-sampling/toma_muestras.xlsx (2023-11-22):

 | 2,61 vp
 | 19 vp | 17,9 Vp |  | 6.86
 |  | 13,45 v
 |  | 223 v | 16.58
 | (Vo * R_dr + Vf ) * a
0
44.51
75.22
115.03
147.67
180.54
213.75
242.76
264.37
285.3
295.87
311.46
322.15
325.67
326.93
327.49
327.27
304.29
270.4
245.37
210
167.35
128.56
84.66
40.87
0
45.42
76.47
116.51
148.92
181.91
213.98
244.01
265.39
285.75
296.9
311.46
322.15
325.67
327.04
327.83
327.15
303.61
270.74
244.92
209.32
168.6
126.97
84.66
40.42

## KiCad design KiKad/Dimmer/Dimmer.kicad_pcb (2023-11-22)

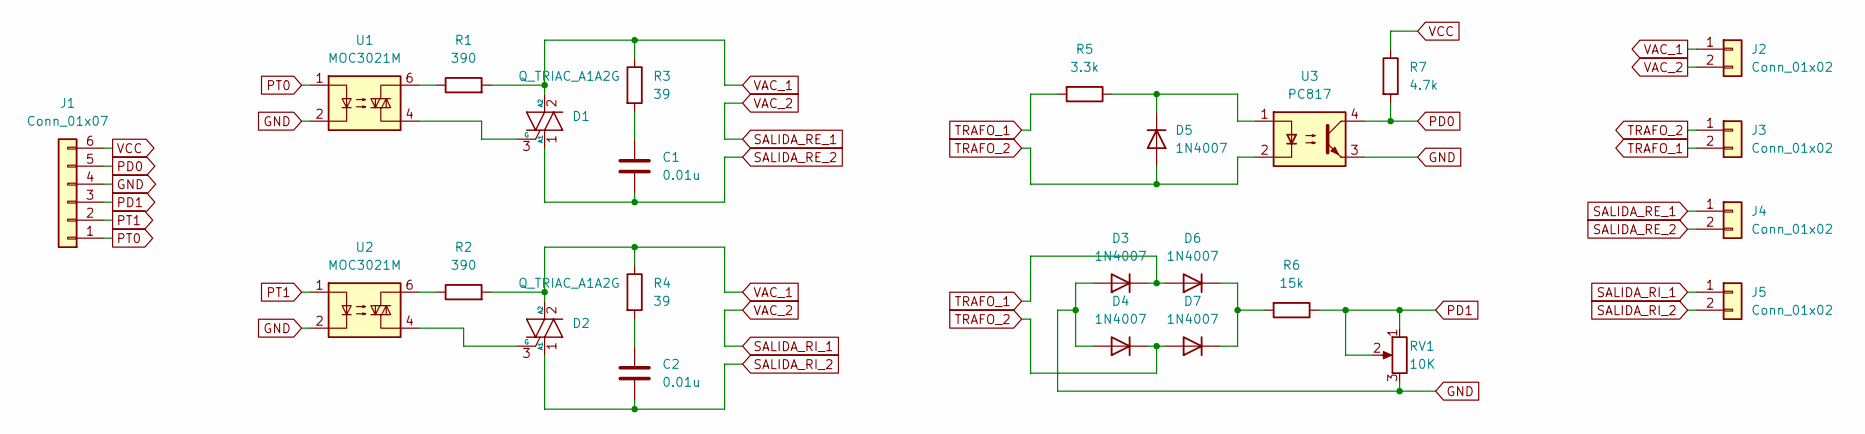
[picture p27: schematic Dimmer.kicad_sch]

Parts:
C1, C2: 0.01u; C_Axial_L5.1mm_D3.1mm_P10.00mm_Horizontal
D1, D2: Q_TRIAC_A1A2G; TO-220-3_Vertical
D3, D4, D5, D6, D7: 1N4007; D_DO-41_SOD81_P10.16mm_Horizontal
J1: Conn_01x07; PinHeader_1x06_P2.54mm_Vertical
J2, J3, J4, J5: Conn_01x02; TerminalBlock_bornier-2_P5.08mm
R1, R2: 390; R_Axial_DIN0207_L6.3mm_D2.5mm_P10.16mm_Horizontal
R3, R4: 39; R_Axial_DIN0207_L6.3mm_D2.5mm_P10.16mm_Horizontal
R5: 3.3k; R_Axial_DIN0207_L6.3mm_D2.5mm_P10.16mm_Horizontal
R6: 15k; R_Axial_DIN0207_L6.3mm_D2.5mm_P10.16mm_Horizontal
R7: 4.7k; R_Axial_DIN0207_L6.3mm_D2.5mm_P10.16mm_Horizontal
RV1: 10K; Potentiometer_Bourns_3296W_Vertical
U1, U2: MOC3021M; DIP-6_W7.62mm_LongPads
U3: PC817; DIP-4_W7.62mm_LongPads

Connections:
GND: D3.2 (A), D4.2 (A), J1.4, RV1.3, U1.2, U2.2, U3.3
unnamed: C1.1, R3.2
unnamed: C2.1, R4.2
unnamed: D1.3 (G), U1.4
unnamed: D2.3 (G), U2.4
unnamed: D5.1 (K), R5.1, U3.1
unnamed: D6.1 (K), D7.1 (K), R6.2
unnamed: R1.1, U1.6
unnamed: R2.1, U2.6
PD0: J1.5, R7.2, U3.4
PD1: J1.3, R6.1, RV1.1, RV1.2
PT0: J1.1, U1.1
PT1: J1.2, U2.1
SALIDA_RE_1: J2.2, J4.1, J5.1
SALIDA_RE_2: C1.2, D1.1 (A1), J4.2
SALIDA_RI_2: C2.2, D2.1 (A1), J5.2
TRAFO_1: D3.1 (K), D6.2 (A), J3.2, R5.2
TRAFO_2: D4.1 (K), D5.2 (A), D7.2 (A), J3.1, U3.2
VAC_1: D1.2 (A2), D2.2 (A2), J2.1, R1.2, R2.2, R3.1, R4.1
VCC: J1.6, R7.1

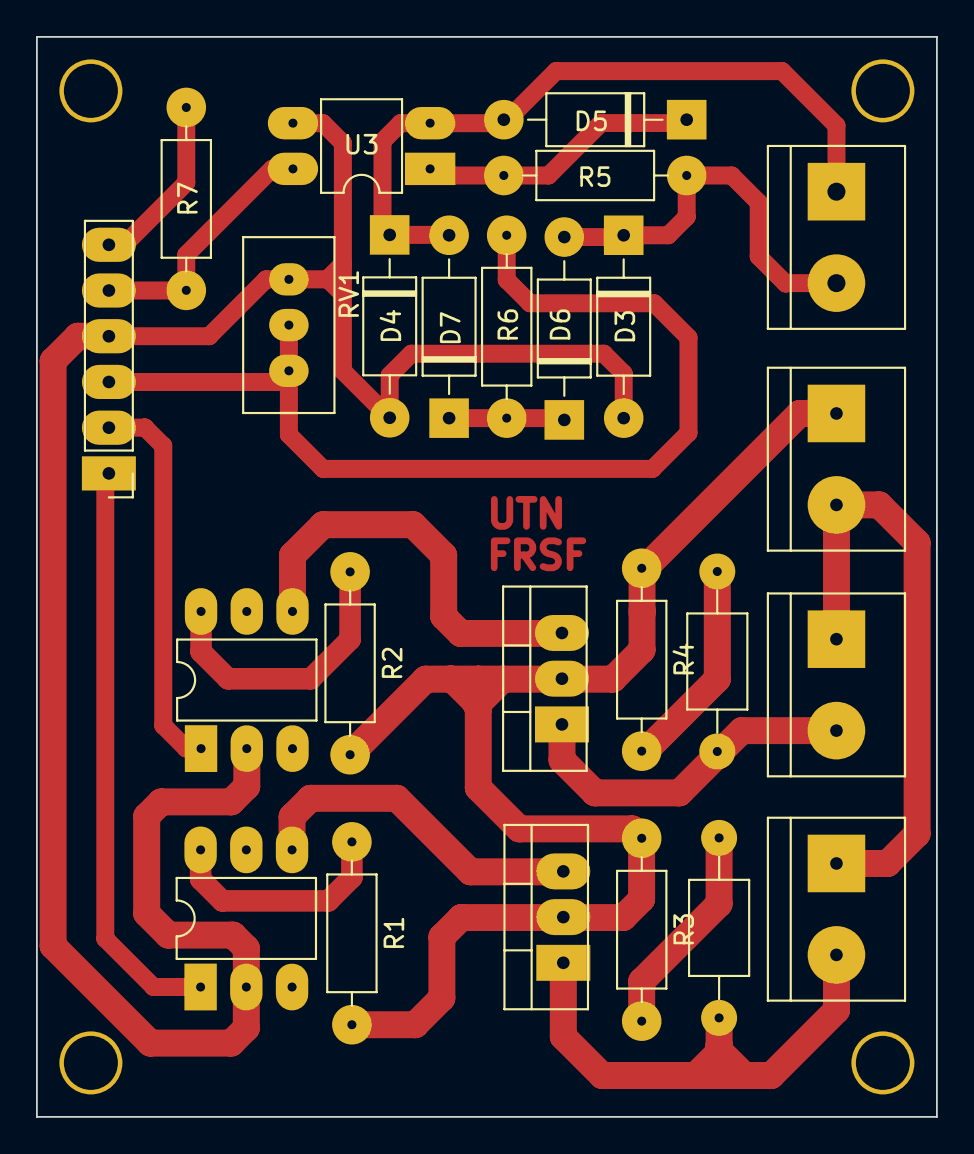
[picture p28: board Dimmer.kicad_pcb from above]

Board: 2 copper layers, 50.0 x 60.0 mm, 25 parts (0 on the bottom side), 20 nets.

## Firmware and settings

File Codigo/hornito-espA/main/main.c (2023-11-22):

// Includes
#include "tasks.h"
//

// Defines

//

// Typedef

//

// ESP-LOG tasks

//

// Handles

//

// Global variables

//

// Function prototypes
//

// Main
void app_main(void){
    setup_time();
    adc_init();
    setup_dimmer_isr();
    setup_wifi();
    initialize_tasks();
    //create_tasks();
    start_webserver();
}
//

// Functions

//

//

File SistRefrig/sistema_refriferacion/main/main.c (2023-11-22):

#include <freertos/FreeRTOS.h>
#include <freertos/task.h>

// Define los pines para las placas Peltier y la bomba
#define PIN_PELTIER_1 
#define PIN_PELTIER_2 
#define PIN_PELTIER_3 
#define PIN_PUMP 

#define SENSING_TIME 5000 //Tiempo de sensado 

// Función para leer la temperatura del sensor (debe ser implementada)
/*
float getTemperature() {
}
*/

void decisionTask(void *pvParameters) {

    gpio_set_direction(PIN_PELTIER_1, GPIO_MODE_OUTPUT);
    gpio_set_direction(PIN_PELTIER_2, GPIO_MODE_OUTPUT);
    gpio_set_direction(PIN_PELTIER_3, GPIO_MODE_OUTPUT);
    gpio_set_direction(PIN_PUMP, GPIO_MODE_OUTPUT);

    while (1) {
        float temperature = getTemperature();

        if (temperature >= 14.0) {
            // Enciende las tres placas Peltier y la bomba
            gpio_set_level(PIN_PELTIER_1, 1);
            gpio_set_level(PIN_PELTIER_2, 1);
            gpio_set_level(PIN_PELTIER_3, 1);
            gpio_set_level(PIN_PUMP, 1);
        } else if (temperature <= 12.0) {
            // Apaga las tres placas Peltier y la bomba
            gpio_set_level(PIN_PELTIER_1, 0);
            gpio_set_level(PIN_PELTIER_2, 0);
            gpio_set_level(PIN_PELTIER_3, 0);
            gpio_set_level(PIN_PUMP, 0);
        } else {
            // Enciende una placa Peltier y la bomba
            gpio_set_level(PIN_PELTIER_1, 1);
            gpio_set_level(PIN_PELTIER_2, 0);
            gpio_set_level(PIN_PELTIER_3, 0);
            gpio_set_level(PIN_PUMP, 1);
        }

        // Espera un tiempo antes de volver a leer la temperatura
        vTaskDelay(pdMS_TO_TICKS(SENSING_TIME));
    }
}

void app_main() {

    xTaskCreate(&decisionTask,
                "Decision Task", 
                configMINIMAL_STACK_SIZE,
                NULL,
                tskIDLE_PRIORITY + 1,
                NULL,
                0);
}

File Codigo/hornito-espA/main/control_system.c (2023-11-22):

#include "control_system.h"

// Defines
#define TASK_CONTROL_SYSTEM_DELAY_MS 5000                               // Milisenconds to wait in the control system tasks
#define US_TO_STEPS 400                                                 // Conversion from microseconds to steps
#define CONTROL_MONITORING_TASK 0                                       // Defines and creates a task that monitors the control system tasks
#define CONTROL_MONITORING_TASK_DELAY_MS 2000                           // Defines the period of the control system monitoring task mentioned above
#define ADC_UNIT ADC_UNIT_1                                             // ADC unit to use
#define NTC1_CHANNEL ADC_CHANNEL_3                                      // ADC channel to use for NTC1

// Handles
static TaskHandle_t xTaskControlSystemGetTemperature_handle = NULL;     // Handle for the get temperature
static TaskHandle_t xTaskControlSystemSendTemperature_handle = NULL;    // Handle for the send temperature
static TaskHandle_t xTaskControlSystemDecision_handle = NULL;           // Handle for the decision
static TaskHandle_t xTaskControlSystemSendSteps_handle = NULL;          // Handle for the send steps
#if CONTROL_MONITORING_TASK
static TaskHandle_t xTaskControlSystemMonitor_handle = NULL;            // Handle for the monitor
#endif
static SemaphoreHandle_t mutexControlSystem = NULL;                     // Mutex to indicate that entry in the critical section
//

// Global variables
bool is_dimmer_disabled = false;
static float setPointTemperature = 60.0;                                // Value of set point temperature
static float temperature = 25.0;                                        // Initial value of temperature
int dimmer_delay_us = 9200;                                             // Initial value of dimmer delay in microseconds
QueueHandle_t xQueueControlSystem;                                      // Queue to send temperature to web
SemaphoreHandle_t xSemaphoreControlSystem;                              // Semaphore to indicate that temperature is ready to send
QueueHandle_t xQueueControlSystemToPower;                               // Queue to send steps to power
SemaphoreHandle_t xSemaphoreControlSystemToPower;                       // Semaphore to indicate that steps are ready to send
//

// ESP-LOG Tags
const static char* TAG_CONTROL = "CONTROL";                             // Tag for the control system
//

// Function prototypes
void create_control_system_tasks();
void create_control_system_semaphores_queues();
void delete_control_system_tasks();
static void vTaskControlSystemDecision();
static void vTaskControlSystemGetTemperature();
static void vTaskControlSystemSendTemperature();
static void vTaskControlSystemSendSteps();
#if CONTROL_MONITORING_TASK
static void vTaskControlSystemMonitor();
#endif
//

// Functions
// Create tasks and mutex for control system
void create_control_system_tasks(){
    if(mutexControlSystem == NULL){
        mutexControlSystem = xSemaphoreCreateMutex();
    }
    
    xTaskCreatePinnedToCore(vTaskControlSystemGetTemperature,
                            "Control System Get Temperature Task",
                            configMINIMAL_STACK_SIZE * 5,
                            NULL,
                            tskIDLE_PRIORITY + 2,
                            &xTaskControlSystemGetTemperature_handle,
                            0);

    xTaskCreatePinnedToCore(vTaskControlSystemSendTemperature,
                            "Control System Send Temperature Task",
                            configMINIMAL_STACK_SIZE * 5,
                            NULL,
                            tskIDLE_PRIORITY + 3,
                            &xTaskControlSystemSendTemperature_handle,
                            1);

    xTaskCreatePinnedToCore(vTaskControlSystemDecision,
                            "Control System Decision Task",
                            configMINIMAL_STACK_SIZE * 5,
                            NULL,
                            tskIDLE_PRIORITY + 1,
                            &xTaskControlSystemDecision_handle,
                            0);

    xTaskCreatePinnedToCore(vTaskControlSystemSendSteps,
                            "Control System Send Steps Task",
                            configMINIMAL_STACK_SIZE * 5,
                            NULL,
                            tskIDLE_PRIORITY + 4,
                            &xTaskControlSystemSendSteps_handle,
                            0); 
    #if CONTROL_MONITORING_TASK
    xTaskCreatePinnedToCore(vTaskControlSystemMonitor,
                            "Control System Monitor Task",
                            configMINIMAL_STACK_SIZE * 5,
                            NULL,
                            tskIDLE_PRIORITY + 1,
                            &xTaskControlSystemMonitor_handle,
                            1);
    #endif

}

void create_control_system_semaphores_queues(){
    xSemaphoreControlSystem = xSemaphoreCreateBinary();
    xSemaphoreControlSystemToPower = xSemaphoreCreateBinary();
    xQueueControlSystem = xQueueCreate(1, sizeof(float));
    xQueueControlSystemToPower = xQueueCreate(1, sizeof(float));
    ESP_LOGI(TAG_CONTROL, "Semaphores and queues created");
}

// Delete tasks for control system
void delete_control_system_tasks(){
    if(xTaskControlSystemGetTemperature_handle != NULL){
        vTaskDelete(xTaskControlSystemGetTemperature_handle);
        xTaskControlSystemGetTemperature_handle = NULL;
    }

    if(xTaskControlSystemSendTemperature_handle != NULL){
        vTaskDelete(xTaskControlSystemSendTemperature_handle);
        xTaskControlSystemSendTemperature_handle = NULL;
    }

    if(xTaskControlSystemDecision_handle != NULL){
        vTaskDelete(xTaskControlSystemDecision_handle);
        xTaskControlSystemDecision_handle = NULL;
    }

    if(xTaskControlSystemSendSteps_handle != NULL){
        vTaskDelete(xTaskControlSystemSendSteps_handle);
        xTaskControlSystemSendSteps_handle = NULL;
    }

    #if CONTROL_MONITORING_TASK
    if(xTaskControlSystemMonitor_handle != NULL){
        vTaskDelete(xTaskControlSystemMonitor_handle);
        xTaskControlSystemMonitor_handle = NULL;
    }
    #endif
}
//

// Task function
// Get temperature from NTC. Before get the temperature, the mutex is taken to indicate that the critical section is in use,
// and then the mutex is given to indicate that the critical section is free, when the temperature is got. 
static void vTaskControlSystemGetTemperature(){
    TickType_t xLastWakeTime = xTaskGetTickCount();
    while (true) {
        if (xSemaphoreTake(mutexControlSystem, portMAX_DELAY)) {
            temperature = get_ntc_temperature_c(get_adc_voltage_mv_multisampling(ADC_UNIT, NTC1_CHANNEL));
            xSemaphoreGive(mutexControlSystem);
        }
        ESP_LOGI(TAG_CONTROL, "NTC1: %.2f °C", temperature);
        vTaskDelayUntil(&xLastWakeTime, pdMS_TO_TICKS(TASK_CONTROL_SYSTEM_DELAY_MS));
    }
}
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

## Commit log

2023-05-18 Agregar programa test adc
2023-06-13 Finalizar código de test de dimmer
2023-08-01 Agregar funcionalidad de medición de resistencia y dimmer mediante archivos .c y .h, no funciona todavía la funcionalidad del dimmer
2023-08-03 Solucionar funcionamiento del dimmer, agregar medición de temperatura con NTC
2023-09-19 Agregar carpeta y diagrama de flujo de sistema de refrigeracion en conjunto con Facu
2023-09-19 Agregar test de tiempo
2023-09-26 Modificacion de diagrama de flujo y agregado de programa de control
2023-09-26 Probar filtro MAV para medicion de temperatura
2023-09-26 Modificar http-test para implementar carga de EPOCH, en conjunto con Manu
2023-09-29 Agregar pinout correcto, remover el otro
2023-09-29 Agregar código test de adc para plottear la señal de entrada al adc
2023-10-03 Solucionar redireccionamiento luego de presionar el botón
2023-10-03 Implementación de tabla con agregado de filas por html
2023-10-13 Diseño PCB Dimmer
    [Dimmer.kicad_pcb, Dimmer.kicad_sch]
2023-10-13 Cambiar nombre de carpeta Código a Codigo para evitar problemas
    [adc.c, dimmer.c, main.c]
2023-10-13 Rediseñar completamente el driver adc
2023-10-18 Añadir recursos linealización de NTC
2023-10-20 Mover funcionalidad del ntc del adc.c/h a ntc.c/h
2023-10-21 Método rudimentario para agregar datos a la tabla de un ntc y tiempo actual
2023-10-24 Agregar código de prueba peltier
2023-10-24 Agregar función de obtención de tensión de adc sin multisampling, arreglos varios y fix de #5
    [adc.c, main.c, ntc.c]
2023-10-29 Arreglar tarea de debugging con el nuevo driver, crear task.c/.h para manejar la creación de tareas de FreeRTOS
    [adc.c, main.c]
2023-11-03 Agregar hoja de datos del NTC de 100k
2023-11-03 Medidor de tensión RMS funcionando
2023-11-07 Agregar tarea para actualización de datos. Incluir botón de inicio
2023-11-07 Agregar sistema de control simple para potencia
2023-11-10 Agregar código vrms en fase, no funcional por lentitud de la tarea
2023-11-10 Agregar código vrms en fase, funcional
    [toma_muestras.xlsx]
2023-11-10 Arreglar sistema de control de alejo, agregar mejoras en la interrupción
    [adc.c, control_system.c, dimmer.c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]
2023-11-10 Agregar botón de guardado y finalización
2023-11-10 Terminar sistema de control
2023-11-10 Implementar semáforo y tarea para cuando el webserver lo pida
2023-11-10 Agregar archivo excel
    [toma2.xlsx]
2023-11-13 Agregar webserver.c y sincronización con power.c
2023-11-13 Acomodar y comentar código de medición de potencia
2023-11-13 Arreglar fórmula de potencia
    [power.c]
2023-11-13 Agregar envio steps a power.c
2023-11-14 Agregar sincronización para actualización de datos
2023-11-14 Agregar comunicación con tarea de sistema de control, modificaciones varias
2023-11-14 Agregar comunicación entre tareas y mejora del sistema de control
2023-11-14 Corregir errores varios del sistema de control de placa fría
    [main.c, peltier.c]
2023-11-14 Modificar excel
    [toma2.xlsx]
2023-11-14 Agregar versión inicial excel de tareas
    [Tareas.xlsx]
2023-11-14 Arreglar creación de mutex y queues según existencia anterior
    [control_system.c]
2023-11-14 Agregar sección critica en el timer y modificar delay de potencia
2023-11-14 Agregar tarea de monitoreo
2023-11-14 Modificar prioridades y núcleos de taras
2023-11-15 Agregar notas excel, modificaciones en prioridades y stack, no funcional el guardado en archivo y eliminación de tareas
    [Tareas.xlsx]
2023-11-15 Agregar comentarios a power.c y corregir arreglo de muestras de float a int
    [power.c]
2023-11-15 Agregar comentarios adc.h y adc.c
2023-11-16 Agregar comentarios y descripcion de codigo
2023-11-16 Arreglar declaración de ISR de dimmer
    [adc.c, dimmer.c]
2023-11-16 Invertir prioridad tarea dimmer y power
2023-11-16 Reducir tamaño de muestras de multisampling y aumentar delay entre medición
2023-11-16 Agregar codigo de creacion de semaforo y queue
2023-11-16 Agregar código de creación de semáforos y colas independiente de la creación de tareas en power.c y control_system.c
2023-11-16 Modificar prioridades tareas
    [Tareas.xlsx]
2023-11-16 Aumentar stack size y mover creación de mutex al inicio de la creación de tareas
2023-11-16 Agregar tarea de monitoreo dimmer.c
2023-11-16 Agregar tarea de monitoreo power.c
2023-11-16 Agregar tarea de monitoreo control_system.c
2023-11-16 Agregar define para la tarea de monitoreo de webserver
2023-11-16 Agregar codigo peltier a hornito-espA
    [Tareas.xlsx]
2023-11-16 Modificar pins, delays y mejorar sistema de toma de mediciones con un semáforo
2023-11-16 Actualizar excel con datos actuales
    [Tareas.xlsx]
2023-11-17 Arreglar control_system.c y webserver I/P
    [control_system.c, power.c]
2023-11-21 Modificacion sistema de control y tiempos
    [Tareas.xlsx]
2023-11-22 Corregir toma de mutex al enviar los steps en control_system.c
2023-11-22 Modificar secuencia de liberación de semáforos
2023-11-23 Mover ejemplos a carpeta aparte, modificar readme
    [toma2.xlsx, toma_muestras.xlsx]
